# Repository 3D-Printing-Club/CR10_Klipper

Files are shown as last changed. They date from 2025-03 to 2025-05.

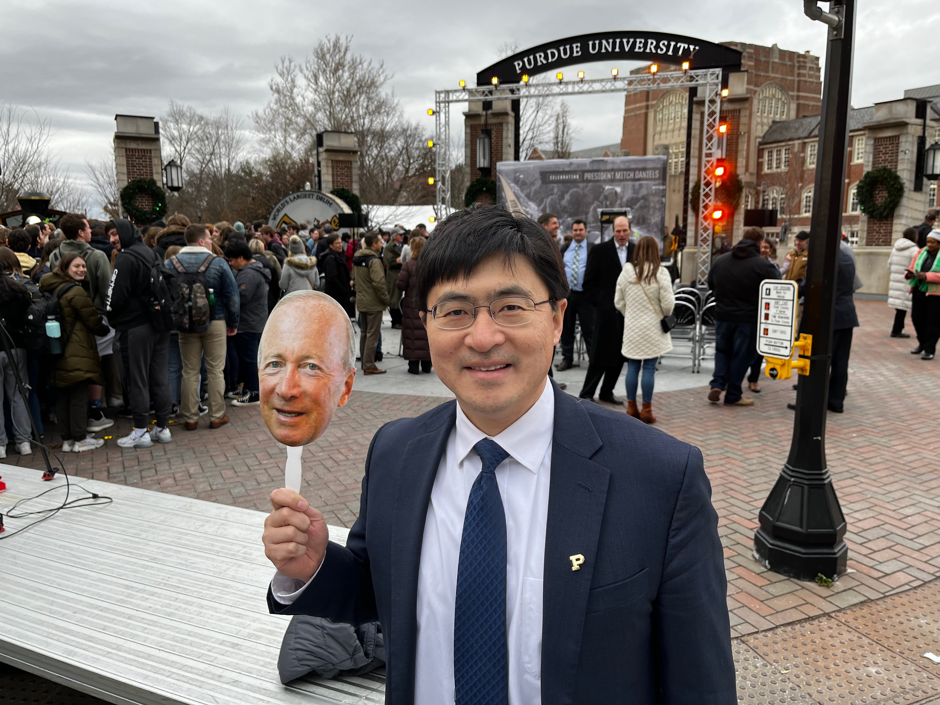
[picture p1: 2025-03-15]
printer_data/config/.fluidd-theme/background.jpg

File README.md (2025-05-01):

# CR10_Klipper
All the config and info for the CR-10 to fix and keep running. 

The CR-10 is currently running off a SKR Mini E3 V3 on klipper. 
It is running a E3D Titan extruder with either a 2.85 or 1.75mm V6 hotend. 
The extrusion system is the Hero ME 7 with some assortment of parts. (https://www.printables.com/model/39322-hero-me-gen7-platform-release4)

This has the Prusa Slicer Profiles, The Klipper configs and some other stuff? The most up to date Klipper configs are under the Klipper branch, not under Main. IDK/ I dont want to fix that right now since it requires me to SSH into the Pi.

---------------
Video for most of the basics i think by Lost in Tech

- https://youtu.be/2nH6lfZ-WvU?si=tElpfwFHICjxLoYV

**Explanation of Klipper and the foundation of the software/firmware:**

The foundation of the CR-10 rn is the Raspberry Pi that runs the website and most of the code and then the MCU which is the control board that controls the motors. We have the Raspi 4 with a SKR Mini E3 V3 running klipper. On this GitHub are the config files for the printer that have all the code that is unique to this printer. There are a lot of little things that are a part of this process but you shall eventually learn when you read all of these docs. 

I'll provide links to more in depth stuff and tutorials of where I looked to learn these things because they're the best reference but I'll try to explain them best I can too. Hopefully you know what klipper is, but if not. It's essentially the foundation of the MCU's firmware. It is the base language that the MCU uses to move the motors. You have Marlin, Duet/Reprap, Octoprint, and Prusa's firmware as other examples. On top of klipper, you have Moonraker which is run on the Pi and essentially makes the webserver that hosts the website. Meaning, Moonraker is the software that runs the website we interact with. Finally, we have fluidd which is the last system and is the stuff we look at. It is the front end system and the UI for all of it. That's the main software that you interact with when the printer is working as expected. When it's not working as expected there are a lot more variables and things to deal with. When you're dealing with a klipper printer, things are either super right or super wrong. Not a lot of in between. Teaching that stuff is a whole new story and you have to be very ready to be able to learn and fix those things. 

The back end for setting this stuff up is actually kinda simple when you learn how to do it. To adjust the deeper settings of Moonraker, or Klipper, or flashing the printer's MCU, or getting the IP address of the printer, or downloading additional software for the system or a whole other bunch of things you're gonna need to enter into the Pi. That's gonna be through a monitor and keyboard, or through SSH. I typically prefer hooking the pi up to a monitor since it feels more reliable and you might not need a password. The passwords for everything are also on the Officer Bitwarden in case they're needed. Including the stuff for the pi and whatnot. Once your into the printer, open up the terminal and open up KIAUH( Klipper Installation and Updating Helper) which does a lot of the harder stuff for you. Type: into the terminal. 

Include link to KIAUH
./KIAUH/KIAUH.sh

And this should get you to the parts you want to fix/adjust. But you almost never should need to go here. 

Other than this, the printer is also linked to a Octoeverywhere account which allows me to check into the printer wherever I am. Which is  set up through the Purdue 3DPC account login and running through KIAUH. 

I think that's all the software stuff that you really need to know?? At least the definitions of things.

Actually working klipper isn't too difficult, a YouTube tutorial will explain it better than I can over text. It's rather simple and there's a tool/macro for most of the things you want to do. But sometimes you might have to make it or find it yourself. I tried to have as much set up as I could but idk. 

Link to how to use Klipper here. 

Then we go into the actual code/ config for the printer. This is where things get messy and personal. The deep dark truth of this printer is that all( most) of the code is stolen from my own config of me CR-10 Mini. The second deep dark truth is that that config is stolen of my Voron V0.1. Which is also stolen from the Voron Design team. So it's a little bit of a mess. The references to V0/V0.1 are about another printer and I never cared to remove those comments. It brings the deeper character.

But trust the code and look up something before you change it. There's a lot to learn and not easy to teach, so I won't do it here, but I'll try to find someone on YouTube who can. Or call me up and I'll explain it. 

YouTube link here.

I don't know what else to explain deeper. Make sure you plug in the Pi, give it a minute to boot, then turn on the printer and probably hit firmware restart in fluidd. 

---------------

**Printer Tidbits/ Hardware:**

Hardware wise it should be pretty simple. The HeroME system is a lot and paywalled for a tutorial, so I'll just include the parts that I printed for it and hope you can piece it together. The Titan extruder on this printer can be switched between 1.75 and 2.85 mm filament because the lab has around 20 spools just sitting around that we want to use up. We probably spent more money fixing the printer than the spools but that's not the point. To switch it from 2.85 to 1.75, all you need to do it switch the tube between the extruder and hotend. Switch the hotend out for the one you'd like. And change the software in Klipper, and Prusa Slicer's filament settings. Maybe a little bit of calibration but that's all. 

We have a 4020 Nocuta Fan to cool the hotend and a 5015 Blower fan to cool the parts. With a E3D V6 hotend system currently running a 0.6 Brass nozzle. A BLTouch for the bed leveling system and PEI bed. 

The main issue of the machine right now is the hotend and movement system. I don't think the pritner can print faster than 5 mm^3/s without issues in appearance which is annoying, but can be fixed later on. The motion system is limiting it a little, but right now it seems to be that the 3mm fillament is slowing the machine down a lot. The motion system and E3D v6 should both be able to run faster than 5mm^3. Once we run out we will really see.

- Dev

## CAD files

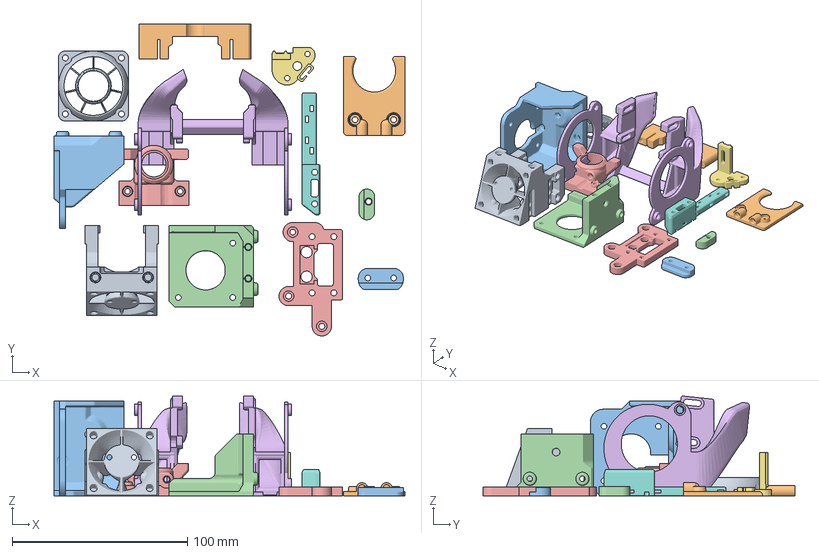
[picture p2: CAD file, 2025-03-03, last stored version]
Cr-10_Printing_parts.3mf
200.1 x 177.9 x 57.0 mm
HMG7.2 Universal Base V2.stl
HMG7.3 Ender 3 V Wheel Belt Bracket.stl
HMG7 E3D-Online Titan Left Mount.stl
HMG7.4 Bondtech BMG BMG-M Front Mount V2.stl
HMG7.3 E3D V6 Revo Six-Dragonfly BMO Collar Mount V3.stl
HMG6-dual-5015-6deg-brace-inserts.stl
HMG7 BLTouch Left Mount.stl
HMG7 Cable Tower Standard Right 10mm.stl
HMG7 Lightweight Fan Guard V2.stl
HMG7 E3D V6-Revo Six-Dragonfly BMO Collar Skirt V2.stl
HMG7.4 Ender 3-Pro-CR10 Long Gantry Clip V2.stl
HMG7.3 CR-10-10S Gantry Clip.stl
HMG7.4 CR-10-10S Gantry Adapter V2.stl

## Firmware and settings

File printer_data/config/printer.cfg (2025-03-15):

[include fluidd.cfg]
[mcu]
serial: /dev/serial/by-id/usb-Klipper_stm32g0b1xx_39004B0015504D5930393520-if00

[include macro.cfg]

[virtual_sdcard]
path: /home/CR10/printer_data/gcodes
on_error_gcode: CANCEL_PRINT

[printer]
kinematics: cartesian
max_velocity: 175
max_accel: 2000
max_z_velocity: 15
max_z_accel: 300
square_corner_velocity: 3


[virtual_sdcard]
path: /home/CR10/printer_data/gcodes

[pause_resume]

[exclude_object]

[display_status]

[exclude_object]

#####################################################################
#      X/Y Stepper Settings
#####################################################################



[stepper_x]
step_pin: PB13
## Refer to https://docs.vorondesign.com/build/startup/#v0
dir_pin: !PB12                                                       # Check motor direction in link above. If inverted, add a ! before PB12
enable_pin: !PB14
rotation_distance: 40
microsteps: 16
full_steps_per_rotation: 200                                        # Set to 400 for 0.9° degree stepper motor, 200 is for 1.8° stepper motors
endstop_pin: tmc2209_stepper_x:virtual_endstop
#   endstop_pin: ^PC0
position_endstop: 0
position_max: 300
homing_speed: 40
homing_retract_dist: 0
homing_positive_dir: false

[tmc2209 stepper_x]
uart_pin: PC11
tx_pin: PC10
uart_address: 0
interpolate: False
run_current: 0.65            
# you need to calculate the run_current value using the equation (rated_motor_current * 0.707 = Maximum_run_current) start with a value that is about 60%-70% of your maximum value.
#sense_resistor: 0.110
stealthchop_threshold: 999999                                            # Set to 999999 to turn stealthchop on, and 0 to use spreadcycle
diag_pin: ^PC0  													# YOU NEED TO JUMP THIS DIAG PIN ON YOUR BOARD FOR SENSORLESS HOMING TO WORK 
driver_SGTHRS: 100                                               # this is set to 255 which is the MAX sensitivity for sensorless homing, you will need to tune this later

[stepper_y]
step_pin: PB10
## Refer to https://docs.vorondesign.com/build/startup/#v0
dir_pin: !PB2                                                        # Check motor direction in link above. If inverted, add a ! before PB2
enable_pin: !PB11
rotation_distance: 40
microsteps: 16
#full_steps_per_rotation: 200                                        # Set to 400 for 0.9° degree stepper motor, 200 is for 1.8° stepper motors
endstop_pin: tmc2209_stepper_y:virtual_endstop
#endstop_pin: ^PC1
position_endstop: 0
position_max: 300
homing_speed: 40
homing_retract_dist: 0
homing_positive_dir: false

[tmc2209 stepper_y]
uart_pin: PC11
tx_pin: PC10
uart_address: 2
interpolate: False
run_current: 0.65            
# you need to calculate the run_current value using the equation (rated_motor_current * 0.707 = Maximum_run_current) start with a value that is about 60%-70% of your maximum value.
# sense_resistor: 0.110
stealthchop_threshold: 999999                                           # Set to 999999 to turn stealthchop on, and 0 to use spreadcycle
diag_pin: ^PC1  													# YOU NEED TO JUMP THIS DIAG PIN ON YOUR BOARD FOR SENSORLESS HOMING TO WORK
driver_SGTHRS: 150                                                  # this is set to 255 which is the MAX sensitivity for sensorless homing, you will need to tune this later

#####################################################################
#   Z Stepper Settings
#####################################################################

[stepper_z]
step_pin: PB0
dir_pin: PC5                                                       # Remove the ! before PC5 if motor direction is inverted.
enable_pin: !PB1
rotation_distance: 8                                                # For T8x8 integrated lead screw
microsteps: 16
endstop_pin: ^PC2
#position_endstop: 0
position_max: 300
position_min: -1.5
homing_speed: 20
second_homing_speed: 3.0
homing_retract_dist: 3.0

[tmc2209 stepper_z]
uart_pin: PC11
tx_pin: PC10
uart_address: 1
interpolate: False
## For OMC (StepperOnline) 17LS13-0404E-200G 0.4A 
#run_current: 0.2
## For LDO-42STH25-1004CL200E 1.0A
run_current: 0.8
sense_resistor: 0.110
stealthchop_threshold: 999999                                            # Set to 999999 to turn stealthchop on, and 0 to use spreadcycle

#####################################################################
#   Extruder
#####################################################################

[extruder]
step_pin: PB3
dir_pin: PB4                                                        # Add ! if moving opposite direction
enable_pin: !PD1
full_steps_per_rotation: 200                                       # Set to 200 for LDO 1.8° stepper motor, and set to 400 for OMC(StepperOnline) 0.9° stepper motor
rotation_distance: 7.718   #Titan Extruder
#rotation_distance: 10.289 #Bondtech DDG Ultimaker                                    # See calibrating rotation_distance on extruders doc
# gear_ratio: 3:1                                                   # For Mini Afterburner
microsteps: 16
nozzle_diameter: 0.400
filament_diameter: 2.85
filament_diameter: 1.750
heater_pin: PC8
## Check what thermistor type you have. See https://www.klipper3d.org/Config_Reference.html#common-thermistors for common thermistor types.
## Use "Generic 3950" for NTC 100k 3950 thermistors
sensor_type: Generic 3950
sensor_pin: PC4
#control: pid                                                        # Do PID calibration after initial checks
#pid_Kp: 22.57
#pid_Ki: 1.72
#pid_Kd: 73.96
min_temp: 0
max_temp: 270
min_extrude_temp: 0
max_extrude_only_distance: 150
max_extrude_cross_section: 0.8
pressure_advance: 0.2                                               # See tuning pressure advance doc
pressure_advance_smooth_time: 0.040


[tmc2209 extruder]
uart_pin: PC11
tx_pin: PC10
uart_address: 3
interpolate: False
## For OMC (StepperOnline) 14HR07-1004VRN 1A 0.9°
#run_current: 0.5   # for OMC 14HR07-1004VRN rated at 1A
## For LDO LDO 36STH17-1004AHG 1A 1.8° 
#run_current: 0.3   # for LDO 36STH17-1004AHG
## For LDO LDO 36STH20-1004AHG 1A 1.8° 
run_current: 0.8   # for LDO 36STH20-1004AHG
sense_resistor: 0.110
stealthchop_threshold: 999999                                            # Set to 0 for spreadcycle, avoid using stealthchop on extruder

#####################################################################
#   Bed Heater
#####################################################################

[heater_bed]
heater_pin: PC9
## Check what thermistor type you have. See https://www.klipper3d.org/Config_Reference.html#common-thermistors for common thermistor types.
## Use "Generic 3950" for Keenovo heaters
sensor_type: ATC Semitec 104GT-2
sensor_pin: PA0
smooth_time: 3.0
#max_power: 0.6                                                     # Only needed for 100w pads
min_temp: 0
max_temp: 110
#control: pid                                                        # Do PID calibration after initial checks
#pid_Kp: 426.68
#pid_Ki: 78.92
#pid_Kd: 576.71

#[verify_heater]
#max_error: 130

#####################################################################
#   Fan Control
#####################################################################

## New Hotendfans
[heater_fan hotend_fan]
pin: PC7      
max_power: 1.0
kick_start_time: 0.8
heater: extruder
heater_temp: 60

#fan_speed: 1.0   
#[heater_fan hotend_fan]
#pin: PC7
#max_power: 1.0
#kick_start_time: 0.05
#heater: extruder
#heater_temp: 50.0
#fan_speed: 1.0                                                     # You can't PWM the delta fan unless using blue wire

[fan]
pin: PC6
max_power: 1.0
kick_start_time: 0.7                                                # Depending on your fan, you may need to increase this value if your fan will not start
off_below: 0.13
cycle_time: 0.010

[fan]
pin: PB15
max_power: 1.0
kick_start_time: 0.7                                                # Depending on your fan, you may need to increase this value if your fan will not start
off_below: 0.13
cycle_time: 0.010

#####################################################################
#   Filament Runout Sensor
#####################################################################

#[filament_switch_sensor Filament_Runout_Sensor]
#pause_on_runout: True
#runout_gcode: PAUSE
#switch_pin: PC15

[bltouch]
sensor_pin: ^PC14
control_pin: PA1
x_offset: -45
y_offset: -7
z_offset: 5
speed: 10

## To be used with BED_SCREWS_ADJUST
[bed_screws]
screw1: 45,255
screw1_name: front right screw
screw2: 45,40
screw2_name: back right screw
screw3: 255,255
screw3_name: front left screw
screw4: 255,40
screw4_name: back left screw

[bed_mesh]
speed: 80
horizontal_move_z: 5
mesh_min: 10, 10       #!!min and max co-ords are based on the probes location not the nozzle!!
mesh_max: 250, 280  #needs to be calibrated for your individual printer
probe_count: 6,6 #this is the number of probing points on X then Y axis
mesh_pps: 2,2
fade_start: 1
fade_end: 10
fade_target: 0
algorithm: lagrange
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

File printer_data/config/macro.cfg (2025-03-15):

#####################################################################
#   Macros
#####################################################################

#################
## Added Macros ~Dev
#########

[gcode_macro Create_Bed_Mesh]
description: Creates a mesh of the entire bed. 
gcode:
  BED_MESH_CALIBRATE




#######################
# Preset Macros
#######################
[gcode_macro PRINT_START]
#   Use PRINT_START for the slicer starting script - please customize for your slicer of choice
gcode:
    G28                            ; home all axes
    G90                            ; absolute positioning    
    G1 Z20 F3000                   ; move nozzle away from bed
   
[gcode_macro PRINT_END]
#   Use PRINT_END for the slicer ending script - please customize for your slicer of choice
gcode:
    M400                           ; wait for buffer to clear
    G92 E0                         ; zero the extruder
    G1 E-4.0 F3600                 ; retract filament
    G91                            ; relative positioning

    #   Get Boundaries
    {% set max_x = printer.configfile.config["stepper_x"]["position_max"]|float %}
    {% set max_y = printer.configfile.config["stepper_y"]["position_max"]|float %}
    {% set max_z = printer.configfile.config["stepper_z"]["position_max"]|float %}

    #   Check end position to determine safe direction to move
    {% if printer.toolhead.position.x < (max_x - 20) %}
        {% set x_safe = 20.0 %}
    {% else %}
        {% set x_safe = -20.0 %}
    {% endif %}

    {% if printer.toolhead.position.y < (max_y - 20) %}
        {% set y_safe = 20.0 %}
    {% else %}
        {% set y_safe = -20.0 %}
    {% endif %}

    {% if printer.toolhead.position.z < (max_z - 2) %}
        {% set z_safe = 2.0 %}
    {% else %}
        {% set z_safe = max_z - printer.toolhead.position.z %}
    {% endif %}

    G0 Z{z_safe} F3600             ; move nozzle up
    G0 X{x_safe} Y{y_safe} F20000  ; move nozzle to remove stringing


    TURN_OFF_HEATERS
    M107                           ; turn off fan
    G90                            ; absolute positioning
    G0 X60 Y{max_y-10} F3600          ; park nozzle at rear
    
[gcode_macro LOAD_FILAMENT]
gcode:
   M83                            ; set extruder to relative
   G1 E30 F300                    ; load
   G1 E15 F150                    ; prime nozzle with filament
   M82                            ; set extruder to absolute
    
[gcode_macro UNLOAD_FILAMENT]
gcode:
   M83                            ; set extruder to relative
   G1 E10 F300                    ; extrude a little to soften tip
   G1 E-40 F1800                  ; retract some, but not too much or it will jam
   M82                            ; set extruder to absolute

[gcode_macro _HOME_X]
gcode:
    # Always use consistent run_current on A/B steppers during sensorless homing
   # {% set RUN_CURRENT_X = printer.configfile.settings['tmc2209 stepper_x'].run_current|float %}
    #{% set RUN_CURRENT_Y = printer.configfile.settings['tmc2209 stepper_y'].run_current|float %}
    #{% set HOME_CURRENT_RATIO = 0.7 %} # by default we are dropping the motor current during homing. you can adjust this value if you are having trouble with skipping while homing
    #SET_TMC_CURRENT STEPPER=stepper_x CURRENT={HOME_CURRENT_RATIO * RUN_CURRENT_X}
    #SET_TMC_CURRENT STEPPER=stepper_y CURRENT={HOME_CURRENT_RATIO * RUN_CURRENT_Y}

    # Home
    G28 X
    # Move away
    # G91
    # G1 X-10 F1200
    
    # Wait for StallGuard registers to clear
    M400
    G90
    # Set current during print
    # SET_TMC_CURRENT STEPPER=stepper_x CURRENT={RUN_CURRENT_X}
    # SET_TMC_CURRENT STEPPER=stepper_y CURRENT={RUN_CURRENT_Y}

[gcode_macro _HOME_Y]
gcode:
    # Set current for sensorless homing
    #{% set RUN_CURRENT_X = printer.configfile.settings['tmc2209 stepper_x'].run_current|float %}
    #{% set RUN_CURRENT_Y = printer.configfile.settings['tmc2209 stepper_y'].run_current|float %}
    #{% set HOME_CURRENT_RATIO = 0.7 %} # by default we are dropping the motor current during homing. you can adjust this value if you are having trouble with skipping while homing
    #SET_TMC_CURRENT STEPPER=stepper_x CURRENT={HOME_CURRENT_RATIO * RUN_CURRENT_X}
    #SET_TMC_CURRENT STEPPER=stepper_y CURRENT={HOME_CURRENT_RATIO * RUN_CURRENT_Y}

    # Home
    G28 Y


    # Move away
    # G91
    # G1 Y-10 F1200

    # Wait for StallGuard registers to clear
    M400
    G90

    # Set current during print
    # SET_TMC_CURRENT STEPPER=stepper_x CURRENT={RUN_CURRENT_X}
    # SET_TMC_CURRENT STEPPER=stepper_y CURRENT={RUN_CURRENT_Y}




[gcode_macro CANCEL_PRINT]
description: Cancel the actual running print
rename_existing: CANCEL_PRINT_BASE
gcode:
  TURN_OFF_HEATERS
  CANCEL_PRINT_BASE

[gcode_macro _HOME_Z]
gcode:
    G90
    G28 Z
    G1 Z30

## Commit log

2025-03-03 Added utilized Hero ME printed parts.
    [Cr-10_Printing_parts.3mf]
2025-03-03 Klipper Config files 3/3/25
2025-03-15 New backup from 15/03/25 - 02:53:52
    [Cr-10_Printing_parts.3mf, macro.cfg, printer.cfg]
2025-04-01 Added Prusa Slicer Config Files
    These have the current setting I'm running them on. For both the 1.75 and 2.85mm. The 1.75mm is still a little more behind due to lack of speed calibration. Trust the 2.85 more than the 1.75
